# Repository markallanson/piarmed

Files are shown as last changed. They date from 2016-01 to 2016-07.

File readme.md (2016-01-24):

Piarmed
=======

Alarm System powered by Raspberry Pi and Node.js.

Install
-------
    cd src
    npm install

Configure
---------
### Enable I2C
### Grant executing user correct privs
The user running piarmed needs the right priviliges to do so.

    sudo adduser <user> i2c
    sudo adduser <user> gpio

### Wire everything up

Run
---
    cd svr
    npm piarmed.js | bunyan

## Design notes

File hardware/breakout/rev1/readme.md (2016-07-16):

This directory contains the eagle schematic and board files for the rev 1
piarmed breakout board.

The rev 1 board contains support for 9 zones, which allows the board to
be the same width as the Raspberry Pi Zero.

# Eagle Parts

## Custom parts
There are 2 custom parts in the piarmed.lbr file in this directory.

### 3x18 Header
I use this with a 3x18 right angle connector from ebay. Actually there is no
such thing, I just got some 3x40 right angle connectors and snipped down to
3x18.

[Sourced from ebay, here] [1].

### Transformer
This is a part to accommodate the placement of a simple small 12v-5v buck
converter.

[Sourced from ebay, here] [2].

## Other parts
The raspberry pi connector is from the [SparkFun Connectors library] [3].

# Inventory
Here's what you will need to assemble the breakout board.

   * 1 - 2x20 2.54mm female header.
   * 1 - 2x20 2.54mm male header.
   * 1 - 3x18 right angle header (doesn't need to be right angle, but this is the way I am assembling it)
   * 1 - [Ebay buck converter] [2].
   * 1 - DC power jack with positive tip polarity.
   * 4 - 3mm LEDS of your favourite colours.
   * 4 - 220ohm resistors. [I used a TE Connectivity resistor - Farnell part 2329900] [4]
   * 18 - 22kohm resistors. [I used a TE Connectivity resistor - Farnell part 2329901] [5]
   * 1 - 1x2 male header (power to Raspberry Pi)
   * 1 - 1x2 female header (to build power cable for the Raspberry Pi)
   * 1 - Micro USB connector

Misc bits
   * Short wires to build power cable
   * Some heat shrink to build power cable.

# Manufacturing
I used [Elecrow] [6] to manufacture the boards. They supply the CAM files and also DRC files
to be used in eagle.

# Known Issues
Rev 1 board has one known issue - the power header to supply the Raspberry Pi is too close to
the Micro USB power port on the Raspberry Pi, so you need to bend your header back towards
the DC power jack in order to make your power cable fit.

[1]: http://www.ebay.co.uk/itm/161947559638
[2]: http://www.ebay.co.uk/itm/171464543948
[3]: https://github.com/sparkfun/SparkFun-Eagle-Libraries
[4]: http://uk.farnell.com/te-connectivity/lr0204f220r/resistor-metal-220r-0-25w-1/dp/2329900
[5]: http://uk.farnell.com/te-connectivity/lr0204f220r/resistor-metal-220r-0-25w-1/dp/2329901
[6]: http://www.elecrow.com/10pcs-2-layer-pcb-p-1175.html

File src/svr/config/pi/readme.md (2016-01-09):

# To Install Device Tree Compiler
Assuming running on a raspbian image. Change if using another distro that does not use apt-get.

    sudo apt-get install device-tree-compiler

# To compile
    dtc -@ -I dts -O dtb -o piarmed-overlay.dtb piarmed-overlay.dts

# To install
    sudo cp piarmed-overlay.dtb /boot/overlays/

# To configure
    sudo vim /boot/config.txt

Add the following line to the end of the file...

    device_tree_overlay=overlays/piarmed-overlay.dtb

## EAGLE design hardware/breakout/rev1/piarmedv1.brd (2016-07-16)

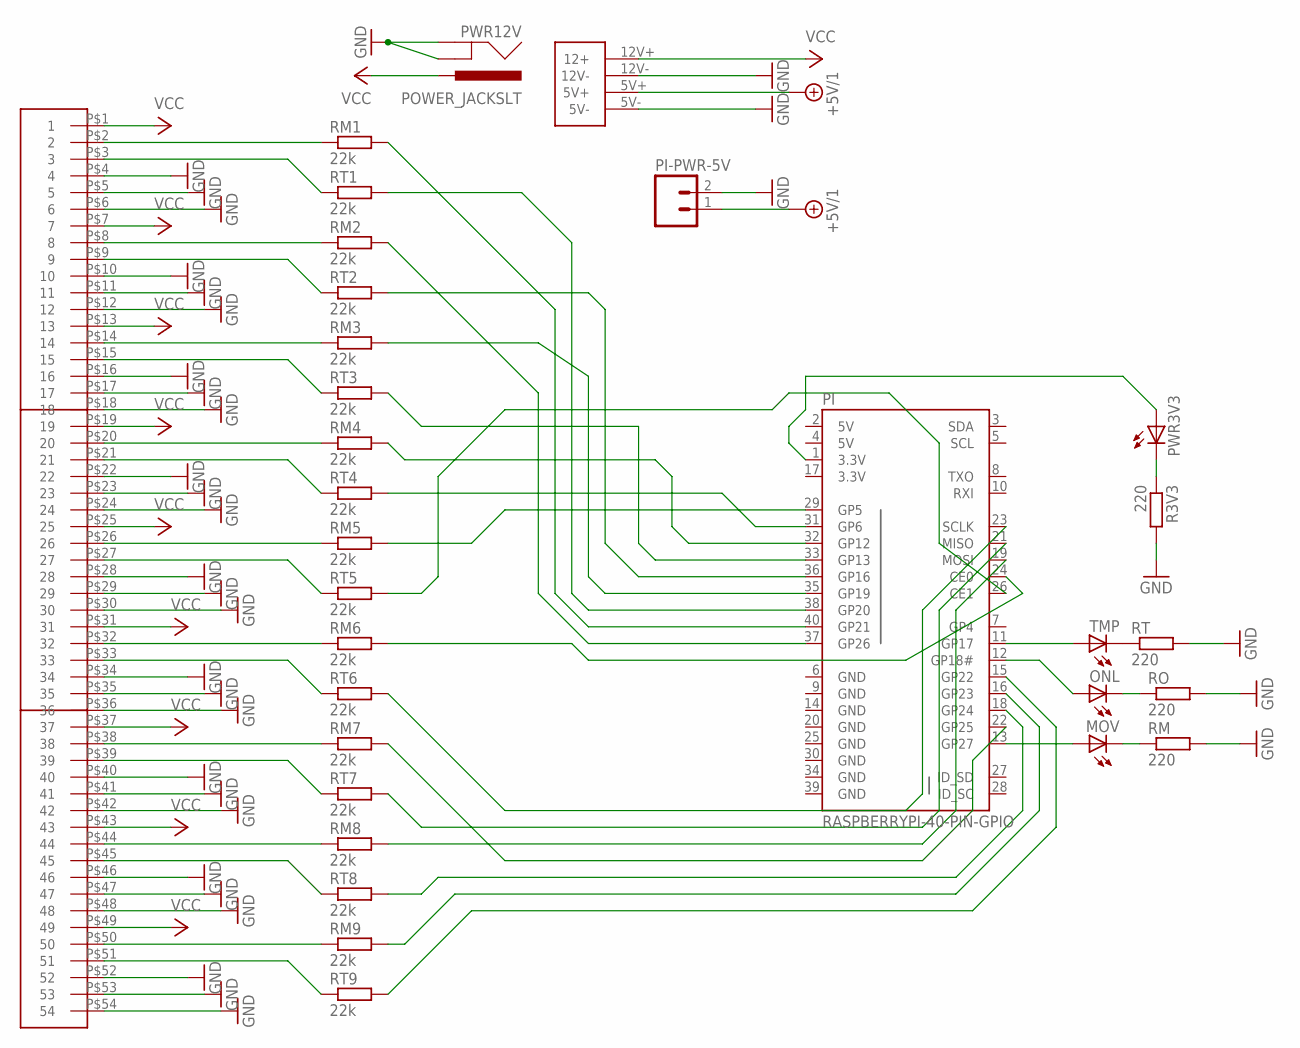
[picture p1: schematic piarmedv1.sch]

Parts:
MOV: LED3MM
ONL: LED3MM
PI: RASPBERRYPI-40-PIN-GPIO; 2X20-SHROUDED
PI-PWR-5V: M02PTH; 1X02
PWR3V3: LED3MM
PWR12V: POWER_JACKSLT; POWER_JACK_SLOT
R3V3: 220; 0204/5
RM: 220; 0204/5
RM1, RM2, RM3, RM4, RM5, RM6, RM7, RM8, RM9: 22k; 0204/5
RO: 220; 0204/5
RT: 220; 0204/5
RT1, RT2, RT3, RT4, RT5, RT6, RT7, RT8, RT9: 22k; 0204/5
TMP: LED3MM
U$1: POWER-12V-5VSTD; 4PIN
U$2: 3X18HEADER

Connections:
3.3V: PI.17 (3.3V)
5V: PI.2 (5V), PI.4 (5V)
+5V/1: PI-PWR-5V.1, U$1.5V+
GND: PI.6 (GND), PI.9 (GND), PI.14 (GND), PI.20 (GND), PI.25 (GND), PI.30 (GND), PI.34 (GND), PI.39 (GND), PI-PWR-5V.2, PWR12V.GND@1 (GNDBREAK), PWR12V.GND@2 (GND), R3V3.2, RM.2, RO.2, RT.2, U$1.5V-, U$1.12V-, U$2.P$4 (4), U$2.P$5 (5), U$2.P$6 (6), U$2.P$10 (10), U$2.P$11 (11), U$2.P$12 (12), U$2.P$16 (16), U$2.P$17 (17), U$2.P$18 (18), U$2.P$22 (22), U$2.P$23 (23), U$2.P$24 (24), U$2.P$28 (28), U$2.P$29 (29), U$2.P$30 (30), U$2.P$34 (34), U$2.P$35 (35), U$2.P$36 (36), U$2.P$40 (40), U$2.P$41 (41), U$2.P$42 (42), U$2.P$46 (46), U$2.P$47 (47), U$2.P$48 (48), U$2.P$52 (52), U$2.P$53 (53), U$2.P$54 (54)
unnamed: PWR3V3.K (C), R3V3.1
unnamed: ONL.K (C), RO.1
unnamed: RT.1, TMP.K (C)
unnamed: MOV.K (C), RM.1
unnamed: ONL.A, PI.12 (GP18#)
unnamed: PI.11 (GP17), TMP.A
unnamed: MOV.A, PI.13 (GP27)
unnamed: PI.40 (GP21), RM1.2
unnamed: PI.38 (GP20), RT1.2
unnamed: PI.37 (GP26), RM2.2
unnamed: PI.36 (GP16), RT2.2
unnamed: PI.35 (GP19), RM3.2
unnamed: PI.33 (GP13), RT3.2
unnamed: PI.32 (GP12), RM4.2
unnamed: PI.31 (GP6), RT4.2
unnamed: PI.29 (GP5), RM5.2
unnamed: PI.26 (CE1), RT5.2
unnamed: PI.24 (CE0), RM6.2
unnamed: PI.23 (SCLK), RT6.2
unnamed: RM1.1, U$2.P$2 (2)
unnamed: PI.21 (MISO), RT7.2
unnamed: PI.19 (MOSI), RM8.2
unnamed: PI.18 (GP24), RT8.2
unnamed: PI.16 (GP23), RM9.2
unnamed: PI.15 (GP22), RT9.2
unnamed: RT1.1, U$2.P$3 (3)
unnamed: RM2.1, U$2.P$8 (8)
unnamed: RT2.1, U$2.P$9 (9)
unnamed: RM3.1, U$2.P$14 (14)
unnamed: RT3.1, U$2.P$15 (15)
unnamed: RM4.1, U$2.P$20 (20)
unnamed: RT4.1, U$2.P$21 (21)
unnamed: PI.22 (GP25), RM7.2
unnamed: RM5.1, U$2.P$26 (26)
unnamed: RT5.1, U$2.P$27 (27)
unnamed: RM6.1, U$2.P$32 (32)
unnamed: RT6.1, U$2.P$33 (33)
unnamed: RM7.1, U$2.P$38 (38)
unnamed: RT7.1, U$2.P$39 (39)
unnamed: RM8.1, U$2.P$44 (44)
unnamed: RT8.1, U$2.P$45 (45)
unnamed: RM9.1, U$2.P$50 (50)
unnamed: RT9.1, U$2.P$51 (51)
POWER: PI.1 (3.3V), PWR3V3.A
VCC: PWR12V.PWR, U$1.12V+ (12+), U$2.P$1 (1), U$2.P$7 (7), U$2.P$13 (13), U$2.P$19 (19), U$2.P$25 (25), U$2.P$31 (31), U$2.P$37 (37), U$2.P$43 (43), U$2.P$49 (49)

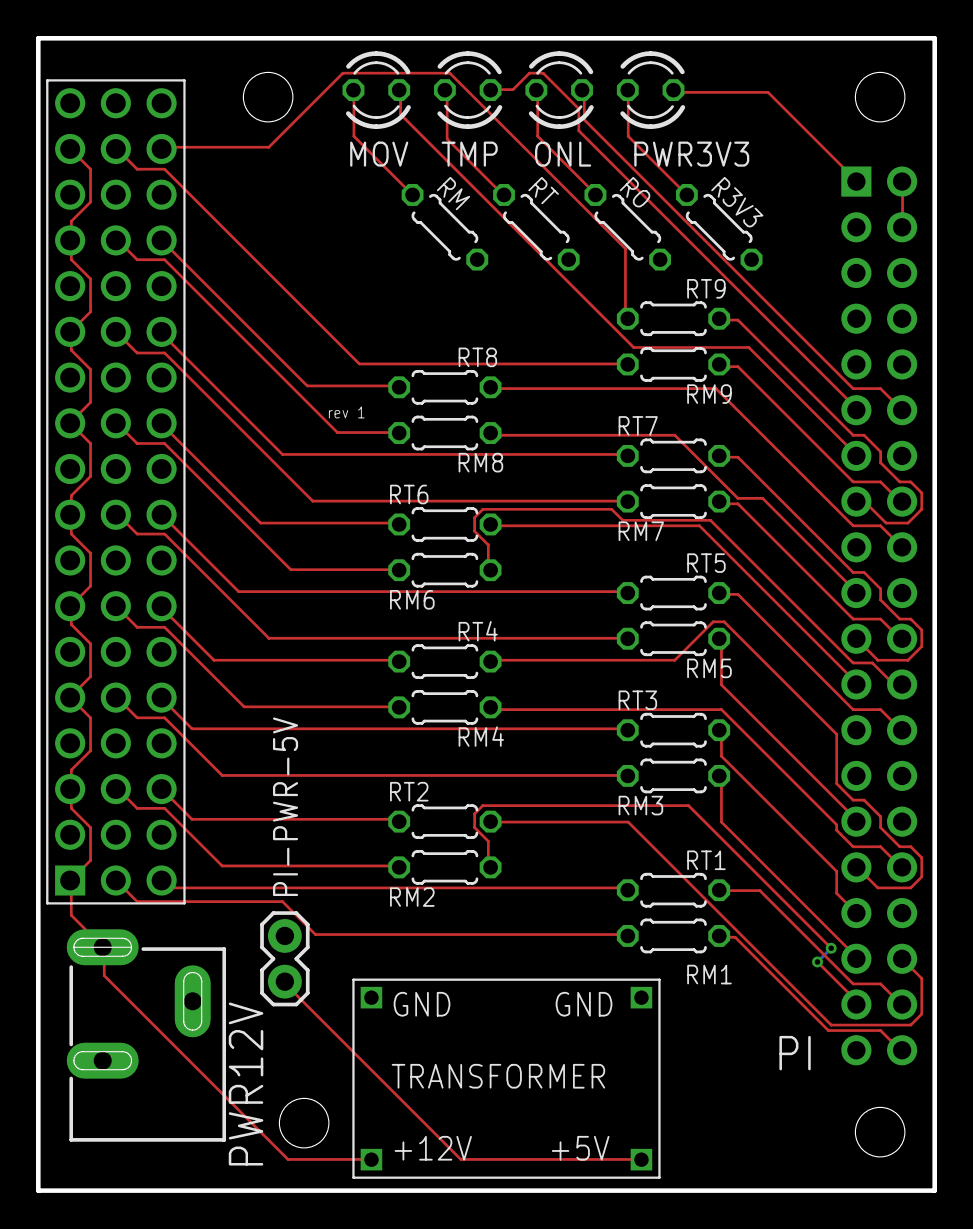
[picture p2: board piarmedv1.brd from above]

Board: 2 copper layers, 49.8 x 64.0 mm, 32 parts (0 on the bottom side), 48 nets.

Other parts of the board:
U$3: 719DPILOGO

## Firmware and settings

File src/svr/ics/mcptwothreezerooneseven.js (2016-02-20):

/* global toString */
"use strict"

const i2c = require("i2c-bus");
const EventEmitter = require("events");
const bunyan = require("bunyan");

/**
 * Implementation of an MCP23017 I/O Expander. <p>
 *
 * Uses a polling loop to read the status of the GPIOA and GPIOB registers
 * then for each configured pin, publishes out the current status.
 *
 * In order to simplify the pin addressing GPIOs are simply labelled
 * from 1 - 16, where 1 is the first pin of GPIOA and 16 is the last
 * pin of GPIOB.
 */
module.exports = function(config) {
    const me = this;
    const log = bunyan.createLogger({ name:"mcp23017-" + config.address });
    me.emitter = new EventEmitter();
    me.set = set;

    const i2cInstance = i2c.openSync(config.bus);

    /** Register Address for reading the A bank of GPIOs */
    const GPIOA_ADDR = 0x12;
    /** Register Address for reading the B bank of GPIOs */
    const GPIOB_ADDR = 0x13;
    /** Register Address for setting the input/output mode of GPIO bank A */
    const IODIRA_ADDR = 0x00;
    /** Register Address for reading the input/output mode of GPIO bank B */
    const IODIRB_ADDR = 0x01;
    /** Regidter for enabling the pullup resistor on the pins of GPIO bank A */
    const GPPUA_ADDR = 0x0c;
    /** Regidter for enabling the pullup resistor on the pins of GPIO bank A */
    const GPPUB_ADDR = 0x0d;

    let icReadFailureCount = 0;

    setup();

    log.info("Polling every ms", config.pollInterval);
    pollLoop();

    /** Sets up the MCP23017 ready to go */
    function setup() {
        log.info("Setting up on Bus", config.bus);
        let inout = 0;
        let pullup = 0;
        config.pins.forEach(function(pin) {
            if (pin.direction === "in") {
                inout = inout | pinMap(pin.id);
            }
            if (pin.pullup) {
                pullup = pullup | pinMap(pin.id);
            }
        });

        log.info("Pin InOut " + inout.toString(2));
        log.info("Pin Pullups " + inout.toString(2));

        // configure the pins for Input or Output.
        // anything unconfigured will be set as an input.
        i2cInstance.writeByteSync(config.address, IODIRA_ADDR, inout);
        i2cInstance.writeByteSync(config.address, IODIRB_ADDR, inout >> 8);

        // enable the pullup resistor for any pins that have requested it.
        i2cInstance.writeByteSync(config.address, GPPUA_ADDR, pullup);
        i2cInstance.writeByteSync(config.address, GPPUB_ADDR, pullup >> 8);
    }

    /**
     * Poll the bus and report the statuses of each configured pin.
     */
    function pollLoop(overrideInterval) {
        // TODO: Only run this loop if we have > 1 pin set to input
        setTimeout(function() {
            // read the two status bytes from the ic
            try {
                const a = i2cInstance.readByteSync(config.address, GPIOA_ADDR);
                const b = i2cInstance.readByteSync(config.address, GPIOB_ADDR);

                // after a successfull read, reset the read failure counter.
                icReadFailureCount = 0;

                // publish the status of each cnfigured pin.
                config.pins.forEach(function(pin) {
                    if (pin.direction === "in") {
                        me.emitter.emit(pin.id.toString(), decode(pin.id, pin.id > 8 ? b : a));
                    }
                });

                // re-enter poll
                pollLoop();
            } catch (e) {
                // if we fail more than 10 times in a row raise an IC read failure alert.
                icReadFailureCount = icReadFailureCount + 1;
                if (icReadFailureCount > 10) {
                    me.emitter.emit("failure", { event: "ic-read-failure", at: me.config});
                }
                log.info("Could not read from IC. Waiting before attempting another retry.", e);

                // TODO: Pull the reset pin on the IC low then high again to initiate a reset.

                // even though we have failed, keep polling in case it comes good.
                pollLoop(2000);
            }
        }, overrideInterval ? overrideInterval : config.pollInterval);
    }

    /**
     * Sets the value on the pin to high or low.
     */
    function set(pin, val) {
        const gpioRegister = pin < 9 ? GPIOA_ADDR : GPIOB_ADDR;
        const existing = i2cInstance.readByteSync(config.address, gpioRegister)
        var updated = encode(pin, val, existing);
        i2cInstance.writeByteSync(config.address, gpioRegister, updated);
    }

    /**
     * Calculates the updated value for the gpio register.
     *
     * Example: Currently Pin 1 and 8 are on, We want to turn on pin 4
     * 10000001 | pinMap(4)
     * 10000001 | 00001000
     * 10001001
     *
     * Example: Currently Pin 1 and 8 and 4 are on, We want to turn off pin 4
     * 10001001 & ~pinMap(4)
     * 10001001 & ~00001000
     * 10001001 & 11110111
     * 10000001
     */
    function encode(pin, val, existing) {
        if (val) {
            return existing | pinMap(pin);
        } else {
            return existing & ~pinMap(pin);
        }
    }

    /**
     * Decode the state of the pin, by anding the gpio state with the bitmask of the pin id
     * then shifting it right by the banks pin id.<p>
     *
     * Example, Pin ID 4 (Bank A, Pin 4 - GPA4 on the datasheet), pin state high.<br />
     * Pin ID 4, PinMapped: 0x08 - 00001000<br />
     * GPIO State: 0x09 - 00001001<br />
     * 00001000 & 00001001 = 00001000<br />
     * 00001000 >> ((4 - 1) % 7) = 00000001<br />
     * Decoded value: 1<p>
     *
     * Example, Pin ID 16 (Bank B, Pin 8 - GPB7 on the datasheet), pin state high.<br />
     * Pin ID 16, PinMapped: 0x80 - 10000000<br />
     * GPIO State: 0xFF - 11111111<br />
     * 10000000 & 11111111 = 10000000<br />
     * 10000000 >> ((16 - 1) % 7) = 00000001<br />
     * 10000000 >> (7) = 00000001<br />
     * Decoded value: 1
     *
     * Pin ID 16, PinMapped: 0x80 - 1000000000000000<br />
     * GPIO State 0xFF - 11111111
     * (pinMap(1000000000000000 >> 8) & 11111111) >> ((16-1) % 8)
     * (pinMap(10000000) & 11111111) >> (15 % 8)
     * (10000000 & 11111111) >> 7
     * 10000000 >> 7
     * 1
     */
    function decode(pinId, gpioState) {
        return (pinMap(((pinId - 1) % 8) + 1) & gpioState) > 0 ? 1 : 0;
    }
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

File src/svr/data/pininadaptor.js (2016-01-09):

"use strict"

const EventEmitter = require("events");
const Gpio = require("onoff").Gpio;

/**
 * A Data adapter that can yield data from a raspberry pi gpio pin directly.
 *
 * The objects emitter, emits a 'data' event, when data is available in
 * both poll and interrupt mode. The data event is never emitted when
 * running in ondemand mode.
 *
 * If an error condition occurs, emits the 'error' event, but will continue
 * processing.
 *
 * Configuration:
 * {
 *   gpio: 9, // The GPIO number to listen to.
 *   mode: "interrupt|poll|ondemand", // what mode to read data in.
 *   pollInterval: 1000 // when in poll mode, how often to read data.
 * }
 */
module.exports = function(config) {
    this.emitter = new EventEmitter();
    this.getValue = getValue;

    let me = this;
    let gpio = null;

    // kick ourselves off in the right mode.
    if (config.mode === "interrupt") {
        startInterrupt();
    } else if (config.mode === "poll") {
        startPoll();
    } else if (config.mode === "ondemand") {
        startOnDemand();
    } else {
        throw Error("Mode " + config.mode + "requested. Only 'interrupt', 'poll' or 'ondemand' supported.");
    }

    console.log("PinInAdaptor started in " + config.mode + " mode on gpio " + config.gpio);

    /**
     * Gets the current value of the pin being monitored.
     */
    function getValue() {
        return gpio.readSync();
    }

    /** Starts the data in adaptor in poll mode. */
    function startPoll() {
        openGpio();
        if (!config.pollInterval) {
            throw Error("Mode set to poll but no pollInterval available");
        }
        pollRead();
    }

    /** Starts the data in adaptor in interrupt mode. */
    function startInterrupt() {
        openGpio('both');
        gpio.watch(function(err, val) {
            if (err) {
                me.emitter.emit('error', err);
            } else {
                emit(val);
            }
        });
    }

    /** Starts the data in adaptor in ondemand mode. */
    function startOnDemand() {
        openGpio();
    }

    /** Opens the gpio ready for input. */
    function openGpio(interruptMode) {
        gpio = new Gpio(config.gpio, 'in', interruptMode);
    }

    function pollRead() {
        setTimeout(function() {
            // emit the value then re-initiate the next read.
            emit(gpio.readSync());
            pollRead();
        }, config.pollInterval)
    }

    /** Emits the specified value as a data event. */
    function emit(val) {
        me.emitter.emit("data", val);
    }
}

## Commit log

2016-01-04 Add an explicit start and stop for the adaptors so we can add support for an initial read. Fixed NC/NO switch information in tamper processing, and rationalized tamper configuration.
2016-01-06 Updated device overlay to add gpio 25
2016-01-09 Added MCP23017 IC support as a source of data. Added software filter between the signal and the PIR in order to do simple noise filtering. GenericPIR now remembers its state and will only broadcast m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
    [mcptwothreezerooneseven.js]
2016-01-24 Now config driven. Added LED Notifiers and outbound data adaption framework. Added bunyan logging. added combos concept and 1 slackbot interface combo.
2016-02-20 Now reacts to presence alerts received via the slack channel to arm and disarm the alarm. Will send notifications to slack if movement is detected while the alarm is armed. Disarming the alarm during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
    [mcptwothreezerooneseven.js]
2016-04-25 Start service, added switch generator.
2016-05-07 Removed ICs from the circuit as modern Pi's have enough GPIO pins to handle my use case.
2016-07-16 Added eagle files for the schematic and board layout for the piarmed breakout board, and a readme to explain some of the details.
    [piarmedv1.brd, piarmedv1.sch]

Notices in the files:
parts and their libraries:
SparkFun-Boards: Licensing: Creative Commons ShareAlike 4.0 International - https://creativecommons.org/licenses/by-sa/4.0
